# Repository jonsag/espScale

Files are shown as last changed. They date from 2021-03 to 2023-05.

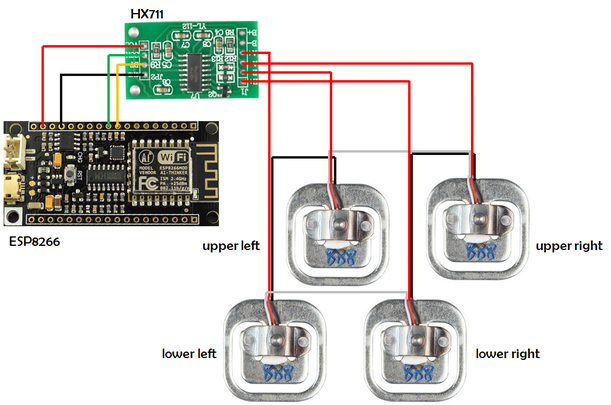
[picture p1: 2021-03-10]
Documents/LoadCellConnections.png

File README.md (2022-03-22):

# espScale

A NodeMCU measuring weight with loadcells

## Setup

Instructions at [https://how2electronics.com/iot-weighing-scale-hx711-load-cell-esp8266/](https://how2electronics.com/iot-weighing-scale-hx711-load-cell-esp8266/)  

Connect four load cells to one amplifier: [https://circuitjournal.com/50kg-load-cells-with-HX711](https://circuitjournal.com/50kg-load-cells-with-HX711)  

Blynk instructions at [https://blynk.io/en/getting-started](https://blynk.io/en/getting-started)  

## Misc

I2C addresses:  
HX711 module: n/a  
LCD screen: 0x27  

Blynk [github](https://github.com/blynkkk/blynk-library)

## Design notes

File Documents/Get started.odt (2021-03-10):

# ESP8266(LiLon NodeMCU V3)

## Get started

Arduino setup (from https://www.instructables.com/id/Getting-Started-With-ESP8266LiLon-NodeMCU-V3Flashi/)

1. File → Preferences…
2. Additional Boards Manager URL: http://arduino.esp8266.com/stable/package_esp8266com_index.json OK
3. Tools → Boards → Boards Manager
4. Search: esp8266 Install
5. Tools → Boards → NODEMCU 1.0 (ESP - 12E Module)

## Pin usage

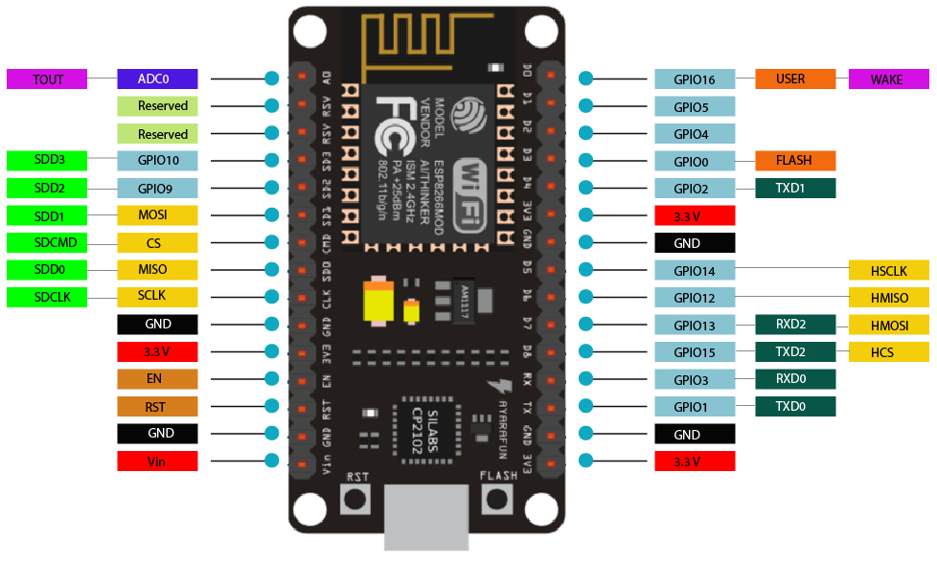
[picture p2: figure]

GPIO Pin | I/O Index Number | Label | Input | Output
GPIO0 | 3 | D3 | pulled up | OK | connected to FLASH button, boot fails if pulled LOW
GPIO1 | 10 | TX | TX pin | OK | HIGH at boot, debug output at boot, boot fails if pulled LOW
GPIO2 | 4 | D4 | pulled up | OK | HIGH at boot connected to on-board LED, boot fails if pulled LOW
GPIO3 | 9 | RX | OK | RX pin | HIGH at boot
GPIO4 | 2 | D2 | OK | OK | often used as SDA (I2C)
GPIO5 | 1 | D1 | OK | OK | often used as SCL (I2C)
GPIO6 | N/A
GPIO7 | N/A
GPIO8 | N/A
GPIO9 | 11
GPIO10 | 12
GPIO11 | N/A
GPIO12 | 6 | D6 | OK | OK | SPI (MISO)
GPIO13 | 7 | D7 | OK | OK | SPI (MOSI)
GPIO14 | 5 | D5 | OK | OK | SPI (SCLK)
GPIO15 | 8 | D8 | pulled to GND | OK | SPI (CS) Boot fails if pulled HIGH
GPIO16 | 0 | D0 | no interrupt | no PWM or I2C support | HIGH at boot, used to wake up from deep sleep
ADC0 | | A0 | Analog input | X

Use either D-number, ie “D0”, or GPIO-number, ie “16”

## Test code

will create a web page to set an LED

#include <ESP8266WiFi.h>

const char* ssid = "Magesh";

const char* password = "jayakumar";

int ledPin = 13; // GPIO13

WiFiServer server(80);

void setup() {

Serial.begin(115200);

delay(10);

pinMode(ledPin, OUTPUT);

digitalWrite(ledPin, LOW);

// Connect to WiFi network

Serial.println();

Serial.println();

Serial.print("Connecting to ");

Serial.println(ssid);

WiFi.begin(ssid, password);

while (WiFi.status() != WL_CONNECTED) {

delay(500);

Serial.print(".");

}

Serial.println("");

Serial.println("WiFi connected");

// Start the server

server.begin();

Serial.println("Server started");

// Print the IP address

Serial.print("Use this URL to connect: ");

Serial.print("http://");

Serial.print(WiFi.localIP());

Serial.println("/");

}

void loop() {

// Check if a client has connected

WiFiClient client = server.available();

if (!client) {

return;

}

// Wait until the client sends some data

Serial.println("new client");

while(!client.available()){

delay(1);

}

// Read the first line of the request

String request = client.readStringUntil('\r');

Serial.println(request);

client.flush();

// Match the request

int value = LOW;

if (request.indexOf("/LED=ON") != -1) {

digitalWrite(ledPin, HIGH);

value = HIGH;

}

if (request.indexOf("/LED=OFF") != -1) {

digitalWrite(ledPin, LOW);

value = LOW;

}

// Set ledPin according to the request

//digitalWrite(ledPin, value);

// Return the response

client.println("HTTP/1.1 200 OK");

client.println("Content-Type: text/html");

client.println(""); // do not forget this one

client.println("<!DOCTYPE HTML>");

client.println("<html>");

client.print("Led pin is now: ");

if(value == HIGH) {

client.print("On");

} else {

client.print("Off");

}

client.println("<br><br>");

client.println("<a href=\"/LED=ON\"\"><button>Turn On </button></a>");

client.println("<a href=\"/LED=OFF\"\"><button>Turn Off </button></a><br />");

client.println("</html>");

delay(1);

Serial.println("Client disonnected");

Serial.println("");

}

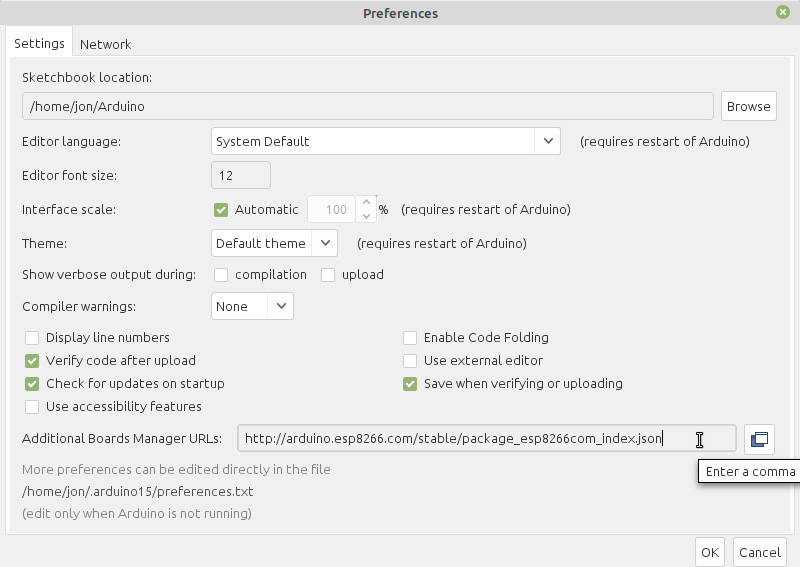
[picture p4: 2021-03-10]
Documents/pictures/Preferences_025.png

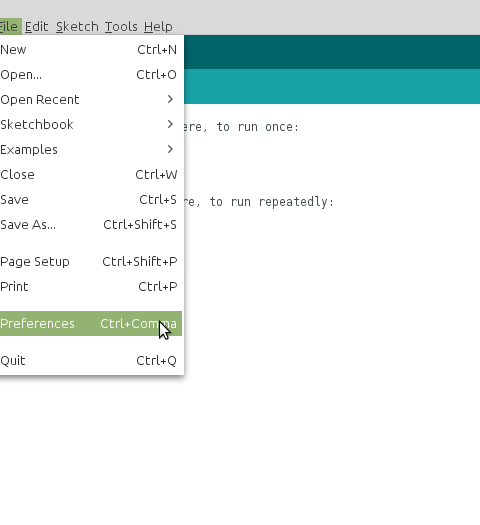
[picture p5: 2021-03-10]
Documents/pictures/Selection_024.png

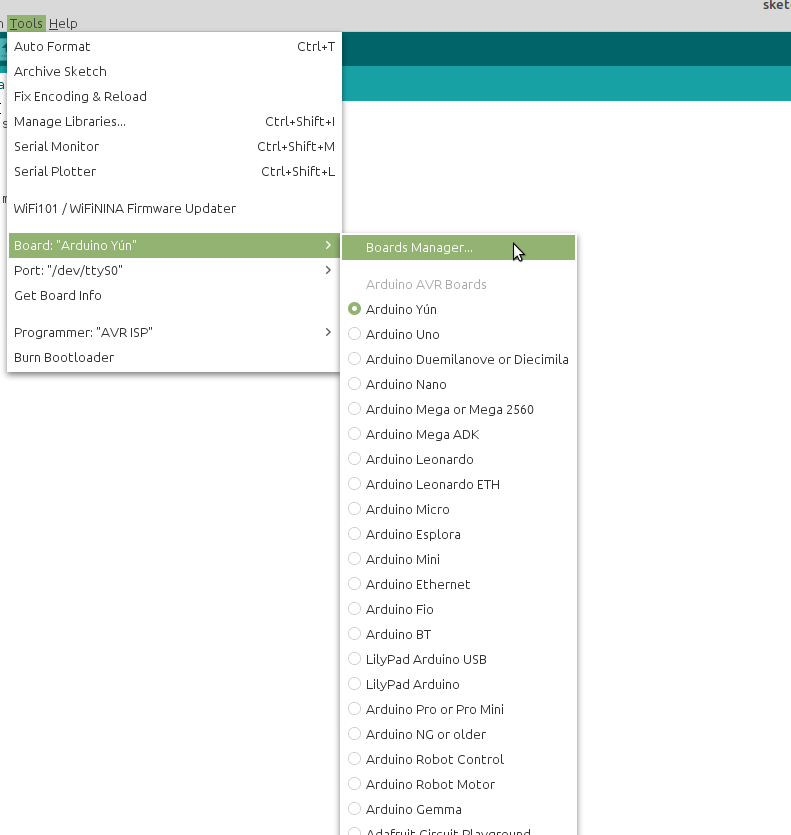
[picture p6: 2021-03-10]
Documents/pictures/Selection_026.png

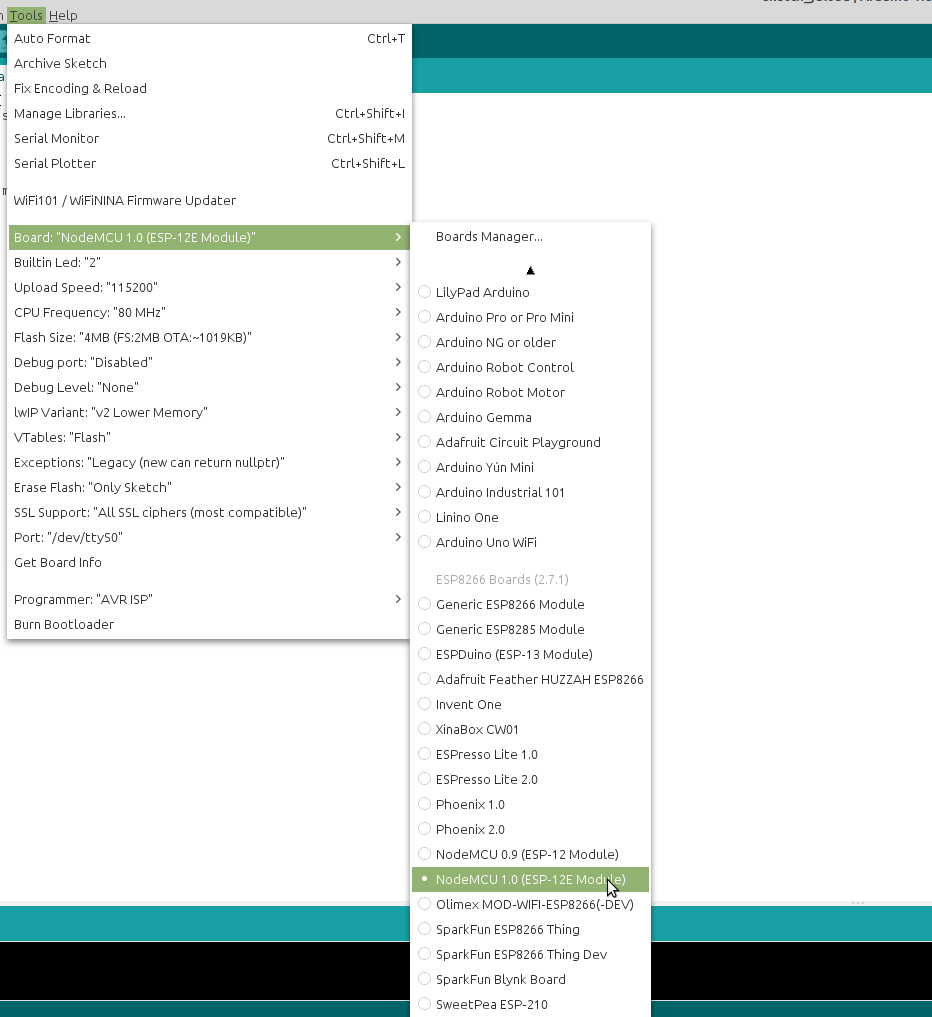
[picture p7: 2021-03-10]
Documents/pictures/Selection_029.png

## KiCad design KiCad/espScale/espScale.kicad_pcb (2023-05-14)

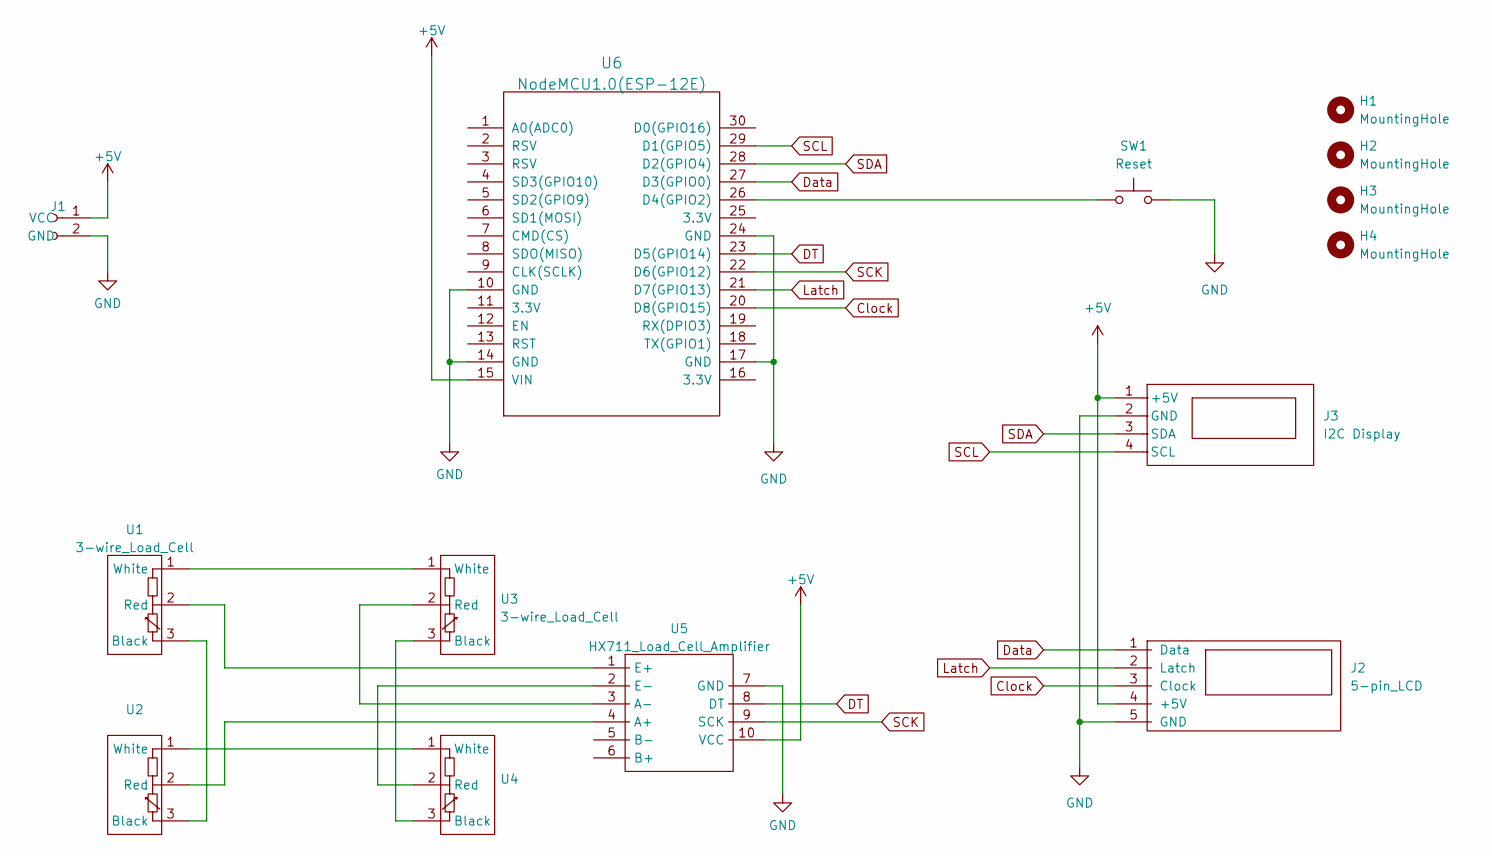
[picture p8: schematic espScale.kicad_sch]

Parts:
H1, H2, H3, H4: MountingHole; MountingHole_3.2mm_M3
J1: 2-pin_power_input_header
J2: 5-pin_LCD; 5-pin JST LiquidCrystal595
J3: I2C Display; 4-pin JST LCD
SW1: Reset; SW_PUSH_6mm_large
U1, U3: 3-wire_Load_Cell; 3-pin JST load cell
U2, U4: 3-pin JST load cell
U5: HX711_Load_Cell_Amplifier; HX711 Load Cell Amplifier w_pinsockets_large
U6: NodeMCU1.0(ESP-12E); NodeMCU-LoLinV3_w_pinsockets_large

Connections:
+5V: J1.1 (VCC), J2.4 (+5V), J3.1 (+5V), U5.10 (VCC), U6.15 (VIN)
Clock: J2.3 (Clock), U6.20 (D8(GPIO15))
DT: U5.8 (DT), U6.23 (D5(GPIO14))
Data: J2.1 (Data), U6.27 (D3(GPIO0))
GND: J1.2 (GND), J2.5 (GND), J3.2 (GND), SW1.2, U5.7 (GND), U6.10 (GND), U6.14 (GND), U6.17 (GND), U6.24 (GND)
Latch: J2.2 (Latch), U6.21 (D7(GPIO13))
unnamed: U1.1 (White), U3.1 (White)
unnamed: U1.2 (Red), U5.1 (E+)
unnamed: U1.3 (Black), U2.3 (Black)
unnamed: U2.1 (White), U4.1 (White)
unnamed: U2.2 (Red), U5.4 (A+)
unnamed: U3.2 (Red), U5.3 (A-)
unnamed: U3.3 (Black), U4.3 (Black)
unnamed: U4.2 (Red), U5.2 (E-)
unnamed: SW1.1, U6.26 (D4(GPIO2))
SCK: U5.9 (SCK), U6.22 (D6(GPIO12))
SCL: J3.4 (SCL), U6.29 (D1(GPIO5))
SDA: J3.3 (SDA), U6.28 (D2(GPIO4))

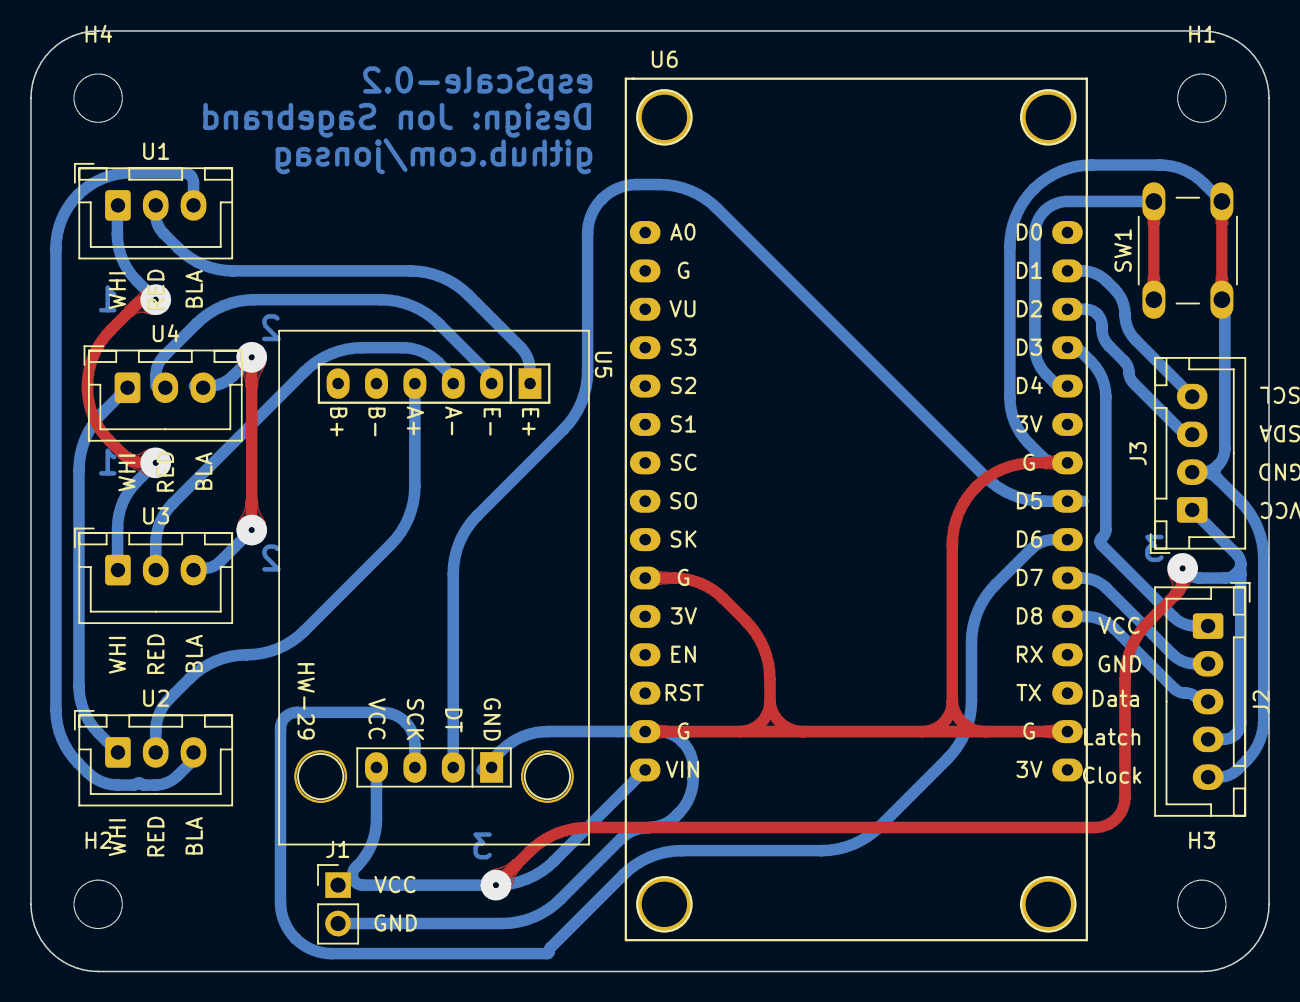
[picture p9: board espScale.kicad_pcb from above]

Board: 2 copper layers, 81.9 x 62.2 mm, 14 parts (0 on the bottom side), 18 nets.

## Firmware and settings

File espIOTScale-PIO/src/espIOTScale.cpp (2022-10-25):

/**********
 * Create a file in this directory called 'secrets.h'
 * This file must have these three lines:
 * const char *ssid = "<your SSID>"; // replace with your wifi ssid and wpa2 key
 * const char *pass = "<your pass>";
 * char auth[] = "<your blynk token>"; // you should get auth token in the Blynk app
 **********/

#include <Arduino.h>

#include "config.h"
#include "secrets.h"

void setup()
{
    Serial.begin(115200);

    /**********
     * Print start information
     ********/
    Serial.println(programName); // print information
    Serial.println(date);
    Serial.print("by ");
    Serial.println(author);
    Serial.println(email);
    Serial.println();

    /**********
     * In/Outputs
     **********/
    Serial.println("Starting In/Outputs...");

    pinMode(rbutton, INPUT_PULLUP);

    /**********
     * Scale
     **********/
    Serial.println("Starting scale...");

    scale.begin(DT, SCK);
    scale.set_scale();
    scale.tare(); // Reset the scale to 0

    long zero_factor = scale.read_average(); // Get a baseline reading

    /**********
     * Blynk
     **********/
    Serial.println("Starting Blynk...");

    Blynk.begin(auth, ssid, pass);

    /**********
     * LCD
     **********/
    Serial.println("Starting LCD...");

#if LCDType == I2C
    lcd.begin();
#elif LCDType == 595
    lcd.begin(lcdColumns, lcdRows);
#endif
    lcd.setCursor(lcdColumns / 2 - 1 - 3 / 2, 0);
    lcd.print("IOT");
    lcd.setCursor(lcdColumns / 2 - 1 - 14 / 2, 1);
    lcd.print("Weighing Scale");

    Serial.println("Waiting 3 seconds...");
    delay(3000);

    lcd.clear();

    /**********
     * WiFi
     **********/
    lcd.print("Connecting Wifi...");

    WiFi.begin(ssid, pass);
    {
        delay(1000);
        Serial.print(".");
        lcd.clear();
    }

    Serial.println("");
    Serial.println("WiFi connected");
    lcd.clear();
    lcd.print("WiFi connected");

    Serial.println("Waiting 2 seconds...");
    delay(2000);

    Serial.println("Starting main program...");
    Serial.println();

    lcd.setCursor(0, 0);
    lcd.print("Measured Weight");
}

void loop()
{
    currentMillis = millis();
    if (currentMillis - lastReadMillis > iterationMillis)
    {
        Blynk.run();

        scale.set_scale(calibration_factor); // Adjust to this calibration factor

        weight = scale.get_units(5);

        if (weight != oldWeight)
        {
            lcd.setCursor(0, 1);
            lcd.print(weight);
            lcd.print(" kg     ");

            oldWeight = weight;
            Blynk.virtualWrite(V3, weight);
        }

        Serial.print("Weight: ");
        Serial.print(weight);
        Serial.println(" kg");
        Serial.println();
    }

    if (digitalRead(rbutton) == LOW)
    {
        scale.set_scale();
        scale.tare(); // Reset the scale to 0
    }
}

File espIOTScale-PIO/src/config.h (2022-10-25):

String programName = "espIOTScale";
String date = "20221025";
String author = "Jon Sagebrand";
String email = "jonsagebrand@gmail.com";

/**********
 * Type of LCD
 **********/
// I2C or 595
#define LCDType I2C

/**********
 * HX711
 **********/
#include "HX711.h" //You must have this library in your arduino library folder

#define DT D5
#define SCK D6

HX711 scale;

// Change this calibration factor as per your load cell once it is found you many need to vary it in thousands
float calibration_factor = -21215; // -21215 worked for my 4x50Kg max scale setup

/**********
 * Serial
 **********/
const int serialSpeed = 115200;

/**********
 * LCD
 **********/
// use the library at https://github.com/fdebrabander/Arduino-LiquidCrystal-I2C-library, not the one installed by Arduino IDE's library manager
#include <Wire.h>

#define lcdColumns 16
#define lcdRows 2

#if LCDType == I2C
#include <LiquidCrystal_I2C.h>

// SCL -> D1
// SDA -> D2

LiquidCrystal_I2C lcd(0x27, lcdColumns, lcdRows);

#elif LCDType == 595
#include <LiquidCrystal595.h> // include the library

#define data D3
#define latch D7
#define clock D8

LiquidCrystal595 lcd(data, latch, clock); // datapin, latchpin, clockpin

#endif

/**********
 * WiFi
 **********/
#include <ESP8266WiFi.h>

WiFiClient client;

/**********
 * Buttons
 **********/
#define rbutton D4 // this button will be used to reset the scale to 0

/**********
 * Blynk
 **********/
#include <Blynk.h>
#include <BlynkSimpleEsp8266.h>

#define BLYNK_PRINT Serial

/**********
 * Misc
 **********/
float weight;
float oldWeight = -1;

unsigned long currentMillis;
unsigned long lastReadMillis = 0;

const int iterationMillis = 2000;

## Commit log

2022-03-22 PIO conversion
    [espScale.kicad_pcb, espScale.kicad_sch]
2022-09-18 kicad page settings
    [espScale.kicad_pcb, espScale.kicad_sch]
2022-10-25 new PCB, added 3-pin LCD
    [espScale.kicad_pcb, espScale.kicad_sch]
2023-05-14 kicad 7
    [espScale.kicad_pcb, espScale.kicad_sch]
